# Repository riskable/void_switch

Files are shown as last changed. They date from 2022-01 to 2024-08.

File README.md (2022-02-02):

# Void Switch OpenSCAD Files
Parametric 3D printable magnetic separation contactless key switch and stabilizers (OpenSCAD files).  For the Kicad files see the [void_switch_kicad](https://github.com/riskable/void_switch_kicad) repo.

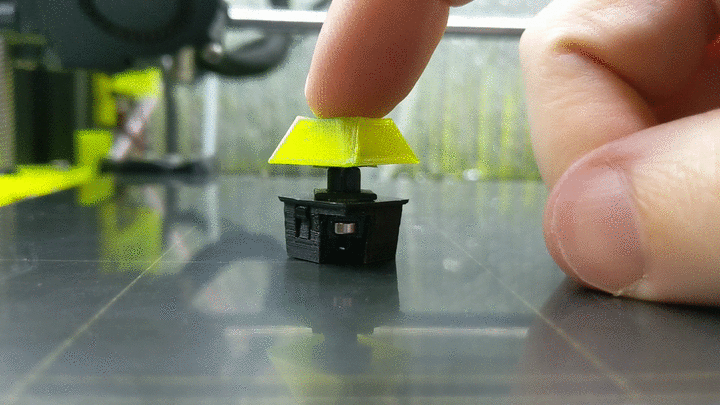
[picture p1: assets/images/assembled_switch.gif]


For a detailed overview of how Void Switches work see Chyrosran22's Teardown video:

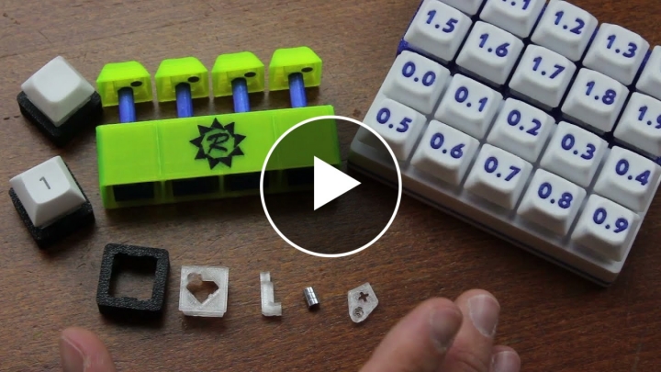
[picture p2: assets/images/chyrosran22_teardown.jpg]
Void Switch Teardown Video (https://youtu.be/H_Ym9528awM)


## BOM
Each switch needs three 4x2mm magnets (Note: Most cheap N35 magnets are actually 4x1.7mm *which is fine*) and the stabilizers require two 4x2mm magnets and some 18 gauge stainless steel wire (make sure it's magnetic; use the cheap stuff).  *Both of these are configurable*, however.  So if you want to make a switch that uses 3x2mm magnets you can do that (with a bit of work changing settings around).

For reference, there's two magnets in the switch itself (one in the sheath and one in the stem) and the levitator needs its own magnet.

## Prerendered files
Prerendered (4mm travel) void switch files are provided in .stl and .3mf format for 4x1.7mm (most common) and 4x2mm magnets with a `MAGNET_VOID` of 0.6mm.  This should make for an all-around decent set of parameters for doing quick tests and demos (to see how the switch feels).  For your own keyboard make sure you try out many different `MAGNET_VOID` values and also try changing the `STEM_TOLERANCE` value to see how you like tighter-fitting or looser-fitting switches.

## Parameters

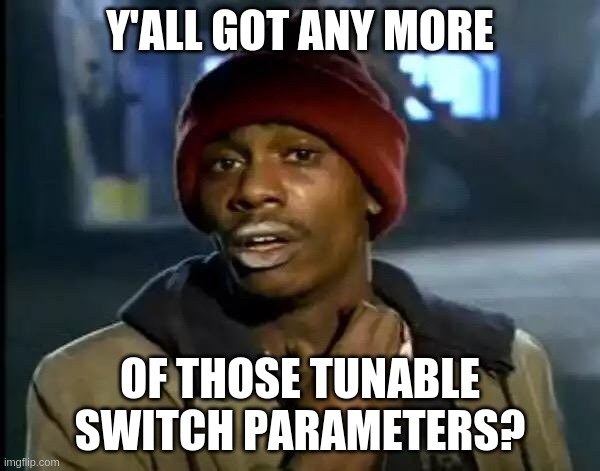
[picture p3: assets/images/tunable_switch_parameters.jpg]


Descriptions of what each parameter does are included in the .scad file and are easily referenced in the OpenSCAD customizer:

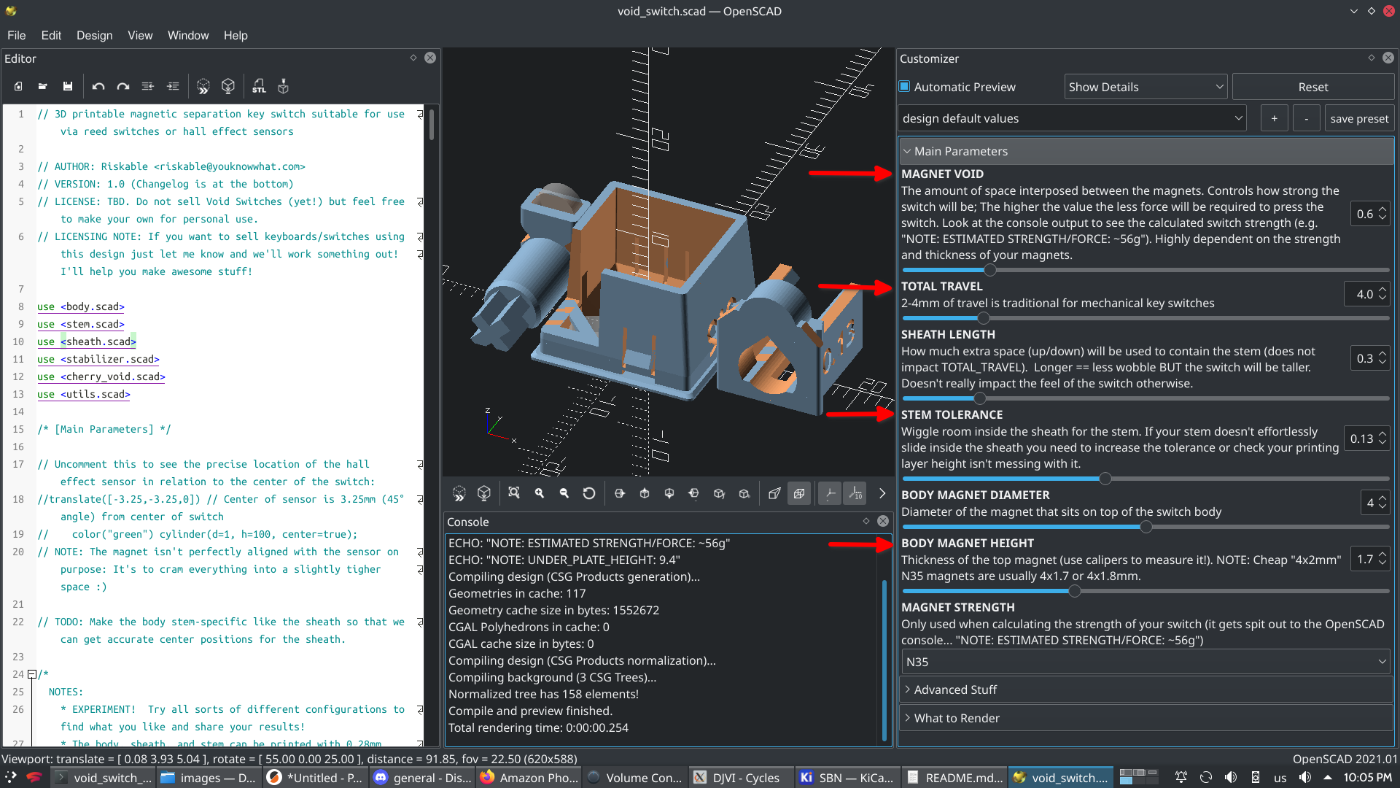
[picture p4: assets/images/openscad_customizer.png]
OpenSCAD Customizer


## Figuring out your switch force/strength
I've added several tables of switch strengths to the `utils.scad` and *pretty good* estimation of how strong your switch will be will show up in the OpenSCAD console.  Here's what it should look like (text enlarged and highlighted for effect):

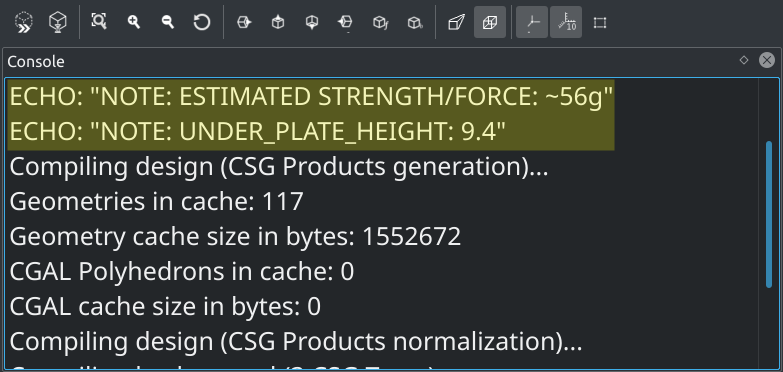
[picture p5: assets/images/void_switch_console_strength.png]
OpenSCAD Console Output


## Print settings
Print the switches and stabilizers at 0.16mm layer height.  This will ensure that the topmost layer of the interior of the sheath ends up with a "close enough" tolerance to your `STEM_TOLERANCE` setting.

The levitator can be printed at just about any layer height but 0.2mm is recommended.

**Note:** It is recommended that the switches be printed in PETG because it has the lowest coefficient of friction of all 3D printable filaments (0.22).  However, PLA also works just fine.  If you use the liquid/oil type of Super Lube w/Syncolon (PTFE) just about *any* filament will work great regardless.  Also note that *you can always just sand the stem* to your perfect level of polished smoothness (don't be lazy).

For reference, even terrible printers seem to do a fine job printined Void Switches.  Because of how the tactility works any bumps or scratchiness in the stems won't be easily felt.  Also, if you print in PETG it has self-lubricating properties when rubbing against itself (it sheds hydrogen atoms which causes a sort of thin molecular collapse at the surface, removing rough/uneven bits).

## Switch assembly
1. Place a magnet in the sheath (using groove jointed pliers makes this super quick and easy).
2. Snap the sheath into the body, pressing the magnet side in first (goes easier that way).
3. Place a magnet in the stem/slider, making sure it's in the correct orientation so as to be attracted to the magnet in the sheath.
4. Slide the stem/slider into the sheath from the underside of the switch.
5. Place a magnet in the levitator, ensuring that *it repels* the magnet in the sheath/body.
6. Place the levitator on the switch stem and then it's ready for a keycap.

**Note:** If you screw up the orientation of the magnets there's little holes so you can pop them out (and reverse them).

**Tip:** Once the sheath is snapped into the body I find it's best to give it a gentle squeeze with some pliers:

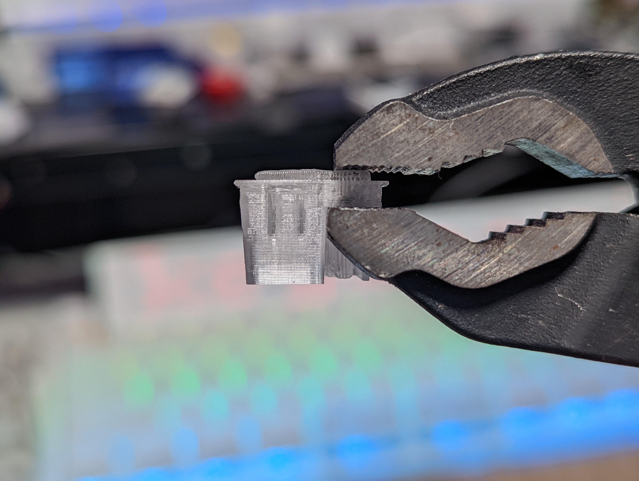
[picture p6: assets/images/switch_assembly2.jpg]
Using pliers on sheath and body together


**Tip:** If you find your magnets aren't staying put (and you don't want to fix the tolerances/print new ones) *you can always just use some glue*.  I find that CA glue (superglue) works great for this.  Just make sure to use the accelerator stuff or it might not stick as well.

## Video tutorials/gifs on how to aseemble Void Switches and stabilizers are coming soon!

I'll also be taking a series of photos and detailing the process here.

## What a keyboard using Void Switches looks like
Here's the keyboard I've been typing on every day for several months:

OpenSCAD Customizer

This is my Riskeyboard 70.  Since Void Switches are entirely contactless I made the case so that the entire top plate could be easily removed (it's magnetically attached with the same 4x2mm magnets used in the switches/stabs).  It makes it *super* easy to clean: Just take the top plate to your kitchen sink and give it a good scrub with soap and water!

## What keycaps to use with Void Switches

Void Switches (currently) use Cherry MX-compatible cross (+) stems so you can use any Cherry-MX compatible keycaps.  Having said that, it is highly recommended that you 3D print your own keycaps for Void Switches!  Try making your own with my [Keycap Playground](https://github.com/riskable/keycap_playground).  3D printed keycaps are superior to injection moulded keycaps in many ways:

 * PETG keycaps _feel_ fantastic!  They also have a very deep sound profile.  PETG is also a fantastic light pipe (that's what it was invented for!) which means multi-material prints with clear legends have the best clarity/brightness.  If you "just use white" PETG you can get very crisp, clear legends and the keycap will light up the same color as your LEDs.
 * PLA keycaps can be made using all sorts of interesting and amazing filaments (_they can have sparkles!_).  They have a sound profile similar to PBT keycaps (high pitch).
 * TPU keycaps are very easy on your fingers and very quiet.  Any 92A or harder TPU can be used for keycaps without any special modifications (yes, the stems will still work fine and won't be "floppy" or whatever).
 * If they break or get ugly or whatever _you can always print new ones_!  For pennies worth of filament!

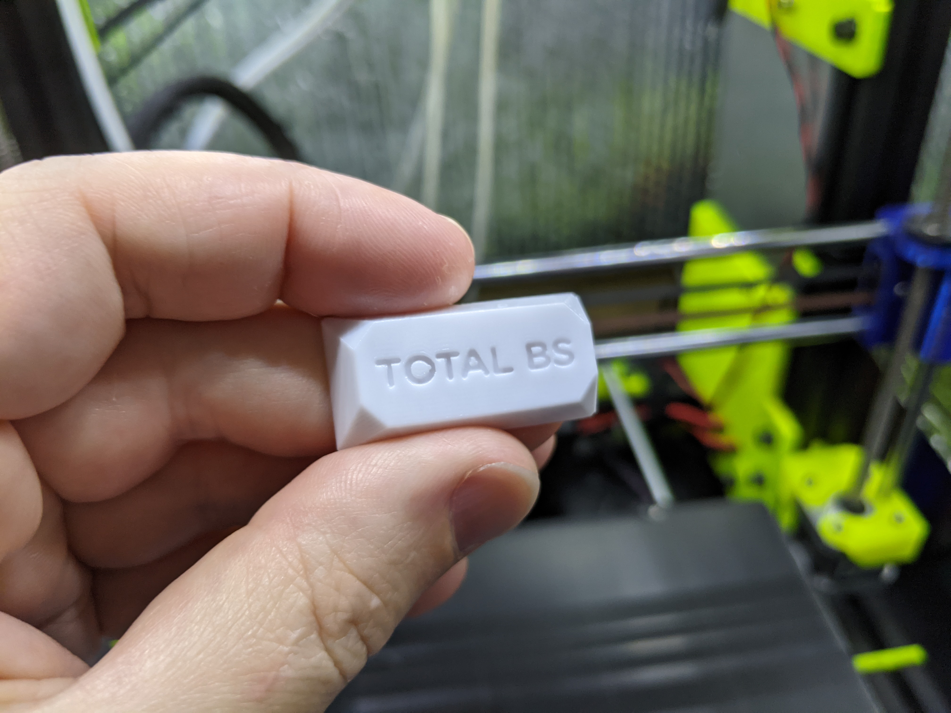
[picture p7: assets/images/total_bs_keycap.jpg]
White PETG TOTAL BS keycap


**NOTE:** Void Switches currently only support the Cherry MX-style cross (+) but support for other stem types can be added (places in the code were carved out for this).  If someone wants to add support for other types feel free to submit a PR.  It might be a better idea to make a stem/slider that simply accepts a "topper" that lets you attach/support an adapter that lets you put whatever stem type you want on there.

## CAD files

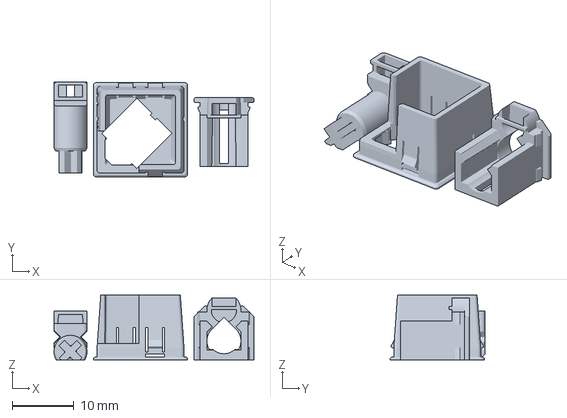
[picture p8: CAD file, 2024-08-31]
3mf/void_switch_2.0_4x1.8mm_1.0_magnet_void_0.2_sheath_length.3mf
32.4 x 15.4 x 10.5 mm

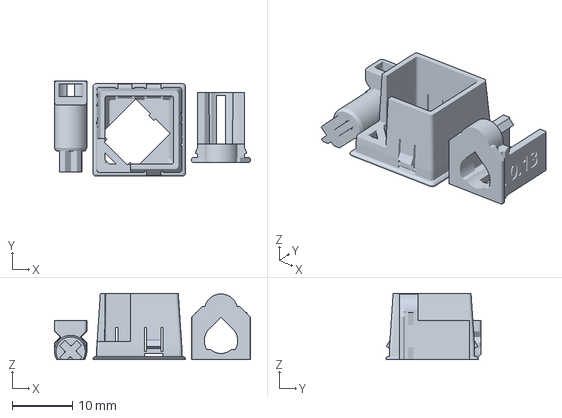
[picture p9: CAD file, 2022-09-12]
3mf/void_switch_4x2mm_0.9_magnet_gap.3mf
32.4 x 15.8 x 10.9 mm

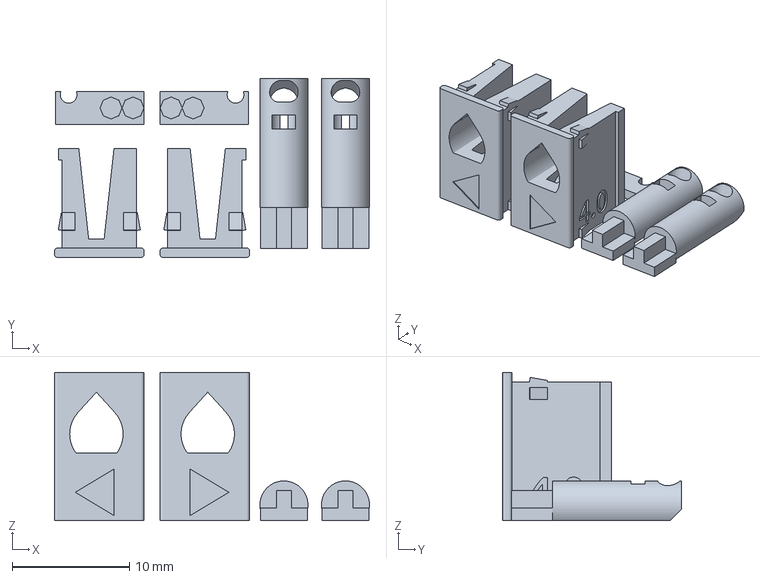
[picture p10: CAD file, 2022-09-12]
3mf/stabilizer_4x2mm_-0.1_void_4mm-travel.3mf
26.9 x 15.3 x 12.6 mm

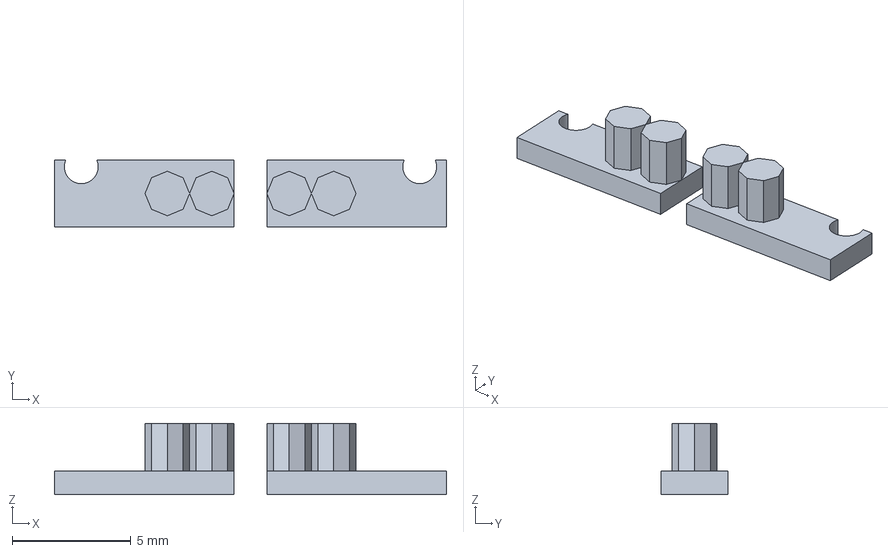
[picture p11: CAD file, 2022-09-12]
3mf/stabilizer_wire_clips.3mf
16.5 x 2.81 x 3.00 mm

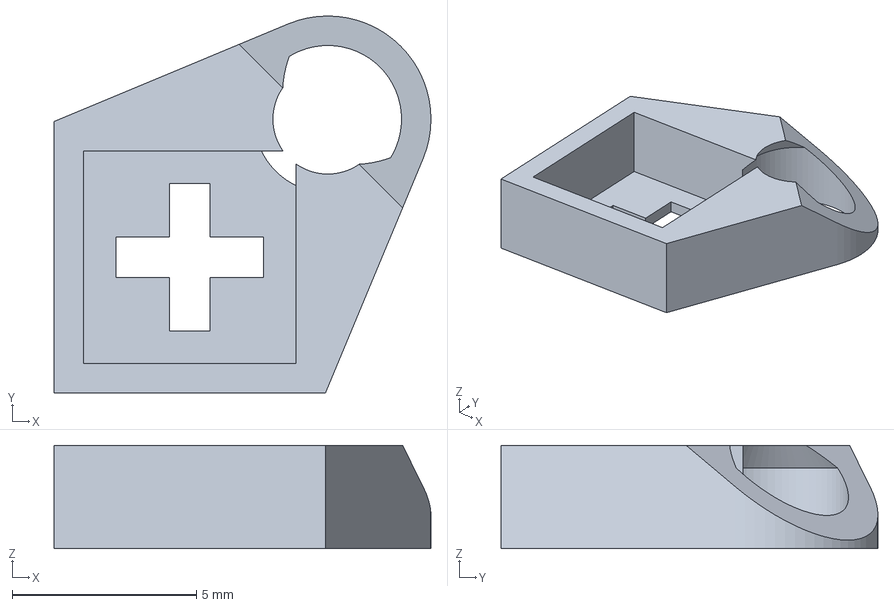
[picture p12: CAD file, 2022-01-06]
3mf/levitator.3mf
10.2 x 10.2 x 2.80 mm

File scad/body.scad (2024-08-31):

// Modules related to the main body of the switch

use <utils.scad>

// Constants
CHERRY_CROSS_LENGTH = 4; // Length of the - and the | in the +

// TODO: Document all these args
// The main housing of the switch that the sheath slides into
module switch_body(length, width, travel, taper=1.1, wall_thickness=1.4, sheath_wall_thickness=1.2, sheath_length=3, cover_overhang=1, cover_thickness=0.6, plate_thickness=1.5, plate_tolerance=0.2, stem_diameter=4.1, sheath_tolerance=0.2, lip_height=1, top_magnet_height=2, top_magnet_diameter=6, top_magnet_cover_thickness=-0.5, magnet_height=1.5, magnet_wall_thickness=0.5, magnet_tolerance=0.15, magnet_void=0.0, sheath_end_stop_thickness=0.8, corner_radius=0.5, droop_extra=0.2, sheath_clip_width=1.5, top_clip_hole_length=2.15, top_clip_hole_width=3.15, stem_tolerance=0.15, bridge_thickness=0.3, sheath_snug_magnet=true, sheath_inside_body=false, height=0) {
    total_travel = travel+top_magnet_height; // Actual total travel
    // How far into the body the stem shroud goes (so we can calculate depth)
    sheath_depth = (
        cover_thickness+sheath_length+total_travel-top_magnet_cover_thickness
        +magnet_height+magnet_wall_thickness*2+magnet_tolerance
        +magnet_void+sheath_end_stop_thickness); // NOTE: Does not include the lip_height on purpose
    body_height = height ? height : sheath_depth; // For clarity in the code
    note(str("BODY_HEIGHT: ", body_height));
    // NOTE: These two sheath variables need to match how they're handled in the actual sheath:
    sheath_width = stem_diameter+sheath_wall_thickness*2;
    sheath_height = stem_diameter+sheath_wall_thickness*2;
    snap_clip_protrusion = 0.2; // How much the little snap lip things stick out from the body (it gets rotate 45° so it's a little less, actually)
    snap_clip_thickness = 0.85; // How thick the clips are
    pin_diameter = 1.875; // Need to match the pin diameter used by the stabilizer clips
    clip_width = width/6;
    clip_side_hole_width = 0.35; // How wide the cutouts are beside each clip
    note(str("UNDER_PLATE_HEIGHT: ", body_height-cover_thickness));
    difference() {
        union() {
            // Generate the part of the body that overhangs the hole on the plate
            translate([0,0,cover_thickness/2])
                hull() { // This is tapered a bit to make removing the switch easier
                    squarish_rpoly(
                        xy=[length+cover_overhang-plate_tolerance/2, width+cover_overhang-plate_tolerance/2],
                        h=cover_thickness,
                        r=corner_radius, center=true);
                    translate([0,0,-cover_thickness/4]) squarish_rpoly(
                        xy=[length+cover_overhang*2-plate_tolerance/2, width+cover_overhang*2-plate_tolerance/2],
                        h=cover_thickness/2,
                        r=corner_radius, center=true);
                }
            // Generate the main body of the switch
            difference() {
                translate([0,0,cover_thickness]) hull() {
                    translate([0,0,plate_thickness/2]) squarish_rpoly(
                        xy=[length-plate_tolerance/2, width-plate_tolerance/2],
                        h=plate_thickness,
                        r=corner_radius, center=true);
                    translate([0,0,body_height-cover_thickness])
                        squarish_rpoly(
                            xy=[length/taper, width/taper],
                            h=cover_thickness/2, // Close enough
                            r=corner_radius, center=true);
                }
                // Cut out the corner so we don't have to worry about a large stem/magnet scraping the sides
                translate([
                  -length/3.75,
                  -width/3.75,
                  body_height/2+top_magnet_height+magnet_wall_thickness+droop_extra-top_magnet_cover_thickness+sheath_length
                  ])
                    cube([length/2,width/2,body_height], center=true);
                difference() {
                // NOTE: Because of the body taper we need to increase the wall thickness here slightly so that it prints well (don't want the slicer cutting off the corners).  That's why we have this "interior bulge" thing...
                    translate([0,0,-cover_thickness/2]) hull() {
                        // NOTE: The interior taper here is to give the wall-to-cover attachment a stronger bond (otherwise the top of the switch can break right off leaving you with a top and a hollow cube)
                        squarish_rpoly(
                            xy=[length-wall_thickness*3.75, width-wall_thickness*3.75],
                            h=cover_thickness/2,
                            r=corner_radius/1.5, center=true);
                        translate([0,0,body_height/4])
                            squarish_rpoly(
                                xy=[length-wall_thickness*2, width-wall_thickness*2],
                                h=cover_thickness/2,
                                r=corner_radius/1.5, center=true);
                        translate([0,0,cover_thickness+sheath_depth+magnet_height+wall_thickness/2])
                            squarish_rpoly(
                                xy=[length/taper-wall_thickness*1.25,
                                    width/taper-wall_thickness*1.25],
                                h=cover_thickness,
                                r=corner_radius/1.5, center=true);
                    }
                }
                // Add a little hole that ensures the bridging goes right
                // TODO: Make these hard-coded numbers like -4.7 take the size of the body into account...
                // Cut out the sides near where the stem presses against the magnet so it doesn't get caught on the sides
                translate([
                  -4.7,
                  -1,
                  top_magnet_height])
                    cube([2,1.6,top_magnet_height*2], center=true);
                translate([
                  -1,
                  -4.7,
                  top_magnet_height])
                    cube([1.6,2,top_magnet_height*2], center=true);
                if (cover_overhang) {
                    // Create a gap underneath the clips so they can move freely
                    gap_size = plate_thickness/2;
                    translate([
                        clip_width,
                        0,
                        cover_thickness/2+gap_size/2])
                            cube([
                                clip_width+clip_side_hole_width*2,
                                width*2,
                                gap_size], center=true);
                    translate([
                        -clip_width,
                        width/2,
                        cover_thickness/2+gap_size/2])
                            cube([
                                clip_width+clip_side_hole_width*2,
                                width/2,
                                gap_size], center=true);
                    // Cutout holes beside the clips so they can bend (slightly) easier when inserting
                    translate([
                        clip_width+clip_width/2+clip_side_hole_width/2,
                        0,
                        cover_thickness/2+travel/2+plate_thickness/2+bridge_thickness])
                            cube([clip_side_hole_width, width*2, travel], center=true);
                    translate([
                        clip_width-clip_width/2-clip_side_hole_width/2,
                        0,
                        cover_thickness/2+travel/2+plate_thickness/2+bridge_thickness])
                            cube([clip_side_hole_width, width*2, travel], center=true);
                    translate([
                        -clip_width-clip_width/2-clip_side_hole_width/2,
                        length/2+snap_clip_protrusion-cover_overhang/1.15,
                        cover_thickness/2+travel/2+plate_thickness/2+bridge_thickness])
                            cube([clip_side_hole_width, width/2, travel], center=true);
                    translate([
                        -clip_width+clip_width/2+clip_side_hole_width/2,
                        length/2+snap_clip_protrusion-cover_overhang/1.15,
                        cover_thickness/2+travel/2+plate_thickness/2+bridge_thickness])
                            cube([clip_side_hole_width, width/2, travel], center=true);
                    // Carve out a bit of the bridge that supports the clips so it can break away easier upon first insertion of the switch into the plate
                    translate([ // Back side left
                        -clip_width,
                        length/2-wall_thickness/1.55,
                        cover_thickness/2+plate_thickness/2+bridge_thickness/2])
                            cube([
                                clip_width+clip_side_hole_width*2,
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

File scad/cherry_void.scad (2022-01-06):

// Riskable's Cherry MX void/cutout module for making keyboard (top) plates and key switch testers

$fn = 32;

use <utils.scad> // Because it's nice to have rounded corners on these sorts of things

// AUTHOR: Riskable <riskable@youknowwhat.com>
// VERSION: 1.1 (Changelog is at the bottom)
// LICENSE: Creative Commons - Attribution - Non-Commercial (if you want to use it in a commercial setting/product just ask!)

// NOTES
/*
    * Feel free to use this .scad in your own projects to add proper Cherry MX-styled switch cutouts to keyboards, perhipherals, testers, or whatever you like.
    * You can just copy cherry_switch_void() into your own code if you like--it's entirely self-contained and reasonably small.  Just make sure to credit it, "// This module was written by Riskable:" or something like that =)
    * Actual Cherry MX Measurements:
        * Length/Width outside dimentions: 15.5mm x 13.95mm
        * Length/Width under the overhang (no "under" on one side though): 13.95mm x 13.95mm
        * In essence, it only overhangs on two sides and the basic cherry "hole" would be 14x14mm
*/

/* Creates the shape of a (proper) Cherry MX switch hole.
    height: The thickness, really.  Doesn't impact PLATE_THICKNESS
    x_extra: Extra (void) space on the X axis (e.g. to save some plastic). Doesn't change the top plate.
    y_extra: Extra (void) space on the Y axis.  Same thing as X.
    tolerance: Extra room on all sides (0.1 default should be good for most printers)
    plate_thickness: How thick the top plate will be. Typical Cherry MX plates are about 1.5mm thick.
*/
module cherry_switch_void(height=12, x_extra=0, y_extra=0, tolerance=0.1, plate_thickness=1.5, corner_radius=0.5) { // Cherry MX body is supposed to be 11.6mm
    switch_width = 15.6;
    switch_length = 14; // Slightly shorter because we're making an acurate profile (see below)
    center_space = 3.5; // Space between the cutouts on the sides of the switch
    sides_width = (5+center_space); // Taken from the Cherry MX developer PDF
    // Make the basic switch shape:
    cube(
        [switch_length+tolerance, switch_length+tolerance, height],
        center=true);
    // Profile for the sides:
    translate([0,sides_width/2,0])
        cube([switch_width-tolerance, center_space+tolerance, height], center=true);
    translate([0,-sides_width/2,0])
        cube([switch_width-tolerance, center_space+tolerance, height], center=true);
    // Fill out the rest with a solid cube so that there's a top plate + empty space beneath
    translate([0,0,plate_thickness])
        squarish_rpoly(
            xy=[switch_width+x_extra, switch_width+y_extra],
            h=height, r=corner_radius, center=true);
}

/*
CHANGELOG:
    1.2: Now using utils.scad with squarish_rpoly() instead of roundedCube since it's better (it's faster *and* I wrote it myself =).
    1.1: Now using roundedCube so the interior edges aren't so sharp.
    1.0: Initial release
*/

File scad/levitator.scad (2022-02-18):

// THE LEVITATOR - Goes under the keycap to provide a cusion of magnetic levitation

// AUTHOR: Riskable <riskable@youknowwhat.com>
// VERSION: 1.0 (Changelog is at the bottom)

/* NOTES:

    * The default configuration works with 4x1 through 4x2mm magnets (anything shorter than 2mm will end up stuck in there just fine--don't worry about it).
    * The default configuration will "eat" 0.4mm of your stem's cross height.  So keycaps won't be able to go all the way down (if you didn't print that part of the stem slightly longer to make up for it).  In testing, losing 0.4mm of height on the cross part of the stem makes absolutely no difference whatsoever.  The keycap still stays on just fine.  I wouldn't worry about it =)

*/

$fn = 64;

use <utils.scad>

// Configurables
LEVITATOR_THICKNESS = 0.4; // How thick the floor will be/how much of the cross part of the stem (+) gets eaten by THE LEVITATOR
WALL_THICKNESS = 0.8; // How thick around the edges you want it to be (0.8 is fine and fits under most keycaps)
STEM_TOLERANCE = 0.15; // How tight the cross-shaped cutout will be
MAGNET_TOLERANCE = 0.2; // Only used with MAGNET_HEIGHT (because we have some bridging)
MAGNET_DIAMETER = 4;
MAGNET_HEIGHT = 2;
MAGNET_DISTANCE = 3.75; // Distance from the center of the stem where the magnet goes

// Constants
CHERRY_CYLINDER_DIAMETER = 5.47; // Represents the keycap's stem (female side of the +)
CHERRY_CROSS_LENGTH = 4; // Length of the - and the | in the +
// We make the cross slightly thinner than normal to keep a tight fit:
CHERRY_CROSS_THICKNESS_X = 1.1; // Width of the - and in the + (Reality: 1.31)
CHERRY_CROSS_THICKNESS_Y = 1.1; // Width of the | in the + (Reality: 1.09)

levitator(MAGNET_DIAMETER, MAGNET_HEIGHT, magnet_distance=MAGNET_DISTANCE, magnet_tolerance=MAGNET_TOLERANCE, wall_thickness=WALL_THICKNESS, thickness=LEVITATOR_THICKNESS, stem_tolerance=STEM_TOLERANCE);
//levitator_double_sided(MAGNET_DIAMETER, MAGNET_HEIGHT, magnet_distance=MAGNET_DISTANCE, magnet_tolerance=MAGNET_TOLERANCE, wall_thickness=WALL_THICKNESS, thickness=LEVITATOR_THICKNESS, stem_tolerance=STEM_TOLERANCE);

// TODO: Finish making this as well as making a matching void space version for top plates:
// This is for the special situations with long ass/heavy spacebars: 
BACKFORCE_LENGTH = 30; // 15mm from the center of the switch on either side
BACKFORCE_WIDTH = 11; // Needs to fit inside/under the keycap but not terribly tight--just enough to prevent it from rotating
//uplifting_jigaroo(BACKFORCE_LENGTH, BACKFORCE_WIDTH, stem_diameter=CHERRY_CYLINDER_DIAMETER, magnet_diameter=4, magnet_height=2, magnet_tolerance=0, wall_thickness=1.2);

module levitator(magnet_diameter, magnet_height, magnet_distance=3.75, magnet_tolerance=MAGNET_TOLERANCE, wall_thickness=0.9, thickness=1, stem_tolerance=0.15) {
    // NOTE: stem_tolerance is the keycap stem; not the switch stem
    height = 2 + wall_thickness; // Just enough to grab the stem
    difference() {
        translate([0,0,height/2]) union() {
            // Main body of the thing
            hull() {
                // NOTE: The square-ish walls around the stem area are just to provide rigidity
                cube([
                    CHERRY_CYLINDER_DIAMETER+wall_thickness*2+stem_tolerance*2,
                    CHERRY_CYLINDER_DIAMETER+wall_thickness*2+stem_tolerance*2,
                    height], center=true);
                translate([magnet_distance,magnet_distance,0])
                    cylinder(d=magnet_diameter+wall_thickness*2, h=height, center=true);
            }
            // Body of the part that holds the magnet (hollowed out below)
            translate([magnet_distance,magnet_distance,0])
                cylinder(d=magnet_diameter+wall_thickness*2, h=height, center=true);
        }
        translate([0,0,-5]) cherry_cross(length=10); // Just don't die on it
        translate([0,0,height/2+thickness+wall_thickness/2]) // Stem cutout
            cube([
                CHERRY_CYLINDER_DIAMETER+stem_tolerance*2,
                CHERRY_CYLINDER_DIAMETER+stem_tolerance*2,
                height+wall_thickness], center=true);
        translate([magnet_distance,magnet_distance,(magnet_height+magnet_tolerance)/2-0.01]) {
            cylinder(d=magnet_diameter, h=magnet_height+magnet_tolerance, center=true);
            // So we can pop the magnet out if we screw up which pole is facing down:
//            rotate([0,0,45])
//                cube([magnet_diameter/3,magnet_diameter/3,100], center=true);
        }
        // Make an angled hole in the top that stops the magnet from coming out while also letting you push it out if needed to flip it around
        translate([magnet_distance,magnet_distance,wall_thickness/2+(magnet_height+magnet_tolerance)-0.01])
            cylinder(d1=magnet_diameter, d2=magnet_diameter/1.5, h=wall_thickness, center=true);
        // Cut off a few bits here and there so it can fit under more keycaps
//        translate([magnet_distance*2+wall_thickness/1.25,magnet_distance*1.25,magnet_diameter/2])
//            cube([magnet_diameter, magnet_diameter*2, magnet_diameter*2], center=true);
//        translate([magnet_distance*1.25,magnet_distance*2+wall_thickness/1.25,magnet_diameter/2])
//            cube([magnet_diameter*2, magnet_diameter, magnet_diameter*2], center=true);
        translate([magnet_distance*1.5,magnet_distance*1.5,magnet_diameter/1.35])
            rotate([0,-50,45])
                cube([magnet_diameter, magnet_diameter*2, magnet_diameter*2], center=true);
    }
}

module levitator_double_sided(magnet_diameter, magnet_height, magnet_distance=3.75, magnet_tolerance=MAGNET_TOLERANCE, wall_thickness=0.9, thickness=1, stem_tolerance=0.15) {
    // NOTE: stem_tolerance is the keycap stem; not the switch stem
    height = 2 + wall_thickness; // Just enough to grab the stem
    difference() {
        translate([0,0,height/2]) union() {
            // Main body of the thing
            hull() {
                // NOTE: The square-ish walls around the stem area are just to provide rigidity
                cube([
                    CHERRY_CYLINDER_DIAMETER+wall_thickness*2+stem_tolerance*2,
                    CHERRY_CYLINDER_DIAMETER+wall_thickness*2+stem_tolerance*2,
                    height], center=true);
                translate([magnet_distance,magnet_distance,0])
                    cylinder(d=magnet_diameter+wall_thickness*2, h=height, center=true);
                translate([-magnet_distance,-magnet_distance,0])
                    cylinder(d=magnet_diameter+wall_thickness*2, h=height, center=true);
            }
            // Body of the part that holds the magnet (hollowed out below)
            translate([magnet_distance,magnet_distance,0])
                cylinder(d=magnet_diameter+wall_thickness*2, h=height, center=true);
        }
        translate([0,0,-5]) cherry_cross(length=10); // Just don't die on it
        translate([0,0,height/2+thickness+wall_thickness/2]) // Stem cutout
            cube([
                CHERRY_CYLINDER_DIAMETER+stem_tolerance*2,
                CHERRY_CYLINDER_DIAMETER+stem_tolerance*2,
                height+wall_thickness], center=true);
        translate([magnet_distance,magnet_distance,(magnet_height+magnet_tolerance)/2-0.01])
            cylinder(d=magnet_diameter, h=magnet_height+magnet_tolerance, center=true);
        translate([-magnet_distance,-magnet_distance,(magnet_height+magnet_tolerance)/2-0.01])
            cylinder(d=magnet_diameter, h=magnet_height+magnet_tolerance, center=true);
        // Make an angled hole in the top that stops the magnet from coming out while also letting you push it out if needed to flip it around
        translate([magnet_distance,magnet_distance,wall_thickness/2+(magnet_height+magnet_tolerance)-0.01])
            cylinder(d1=magnet_diameter, d2=magnet_diameter/1.5, h=wall_thickness, center=true);
        translate([-magnet_distance,-magnet_distance,wall_thickness/2+(magnet_height+magnet_tolerance)-0.01])
            cylinder(d1=magnet_diameter, d2=magnet_diameter/1.5, h=wall_thickness, center=true);
        // Cut off a few bits here and there so it can fit under more keycaps
        translate([magnet_distance*1.5,magnet_distance*1.5,magnet_diameter/1.35])
            rotate([0,-50,45])
                cube([magnet_diameter, magnet_diameter*2, magnet_diameter*2], center=true);
        translate([-magnet_distance*1.5,-magnet_distance*1.5,magnet_diameter/1.35])
            rotate([0,50,45])
                cube([magnet_diameter, magnet_diameter*2, magnet_diameter*2], center=true);
    }
}
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

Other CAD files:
3mf/void_switch_4x1.7mm_0.9_magnet_gap.3mf
3mf/void_switch_4x2mm_0.6_magnet_gap.3mf
3mf/void_switch_4x1.7mm_0.6_magnet_gap.3mf
scad/sheath.scad
scad/sheath_negative.scad
scad/stabilizer.scad
scad/stem.scad
scad/utils.scad
scad/void_switch.scad
stl/levitator.stl
stl/stabilizer_4x2mm_-0.1_void_4mm-travel.stl
stl/stabilizer_wire_clips.stl
stl/void_switch_4x2mm_0.6_magnet_gap.stl
stl/void_switch_4x2mm_0.9_magnet_gap.stl

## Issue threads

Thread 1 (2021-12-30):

Love these switches

C1ARKGABLE, 2021-12-30:
Saw [this YouTube video](https://www.youtube.com/watch?v=H_Ym9528awM) and had to find where I could get these switches. I'd love to try printing a low profile set.

Have you thought about potentially adding elector magnets to tune the key characteristics on the fly?

Keep up the great work

C1ARKGABLE, 2021-12-30:
Not an issue, just wanted to comment

riskable, 2022-01-03:
Haha I made this repo *in preparation* for releasing my switch files.  They're not quite ready yet.  Very soon though :smile:

Closed 2021-12-30.

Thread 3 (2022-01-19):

Just a question: Minimum practical size?

kubycsolutions, 2022-01-19:
Lovely design, and many thanks for parameterizing and documenting it so well.

Apologies if I've missed this one in the docs: Have you done any experiments to see what the minimum center-to-center distance could be while still operating well? I have an button-matrix application where that's about half an inch; full-size keyboards run closer to 3/4".

riskable, 2022-01-20:
The distance from the center of the switch to the magnet is 3.25mm (it's hard coded--for now) and the diagonal width of the sheath is ~12mm.  So the minimum width/length of the switch with default settings is going to be 12mm+some space for wall thickness so it *should* fit within 0.5inches (12.7mm).

Another thing you can do is use 3x2mm magnets instead of 4x2mm...  Then you can decrease the `STEM_DIAMETER` and you'll end up with a sheath that's skinnier.  You can also try setting `STABILIZER_STEM = true;` which will give you a stem with a + that's flat instead of at a 45° angle.  This would enable you to place the sheath into the body (or just a top plate with the correct cutout shape) horizontally instead of vertically.  Just make sure your sensors are 3.25mm away from the center of the footprint and it should work fine.  In this situation you'd be making a switch that had the magnet just below or above the center of the switch instead of diagonally in the corner.

There's all sorts of other values you can play with to squeeze the switch into a tighter space like WALL_THICKNESS, MAGNET_WALL_THICKNESS, etc etc.  You can also use a smaller magnet in the stem but keep the body magnet the usual 4x2mm size (mix & match).  You *may* have to go into sheath.scad and fudge a few of the values to make things line up though.  If you read the comments I have loads of info about places where that might be necessary for certain types of adjustments.

kubycsolutions, 2022-01-20:
Many thanks once again!--Sent from palmtop; apologies for any auto-incorrections.() | ASCII Mail Campaign/\ | Stamp out HTML mailOn Jan 20, 2022 9:36 AM, Riskable ***@***.***> wrote:

The distance from the center of the switch to the magnet is 3.25mm (it's hard coded--for now) and the diagonal width of the sheath is ~12mm.  So the minimum width/length of the switch with default settings is going to be 12mm+some space for wall thickness so it should fit within 0.5inches (12.7mm).

Another thing you can do is use 3x2mm magnets instead of 4x2mm...  Then you can decrease the STEM_DIAMETER and you'll end up with a sheath that's skinnier.  You can also try setting STABILIZER_STEM = true; which will give you a stem with a + that's flat instead of at a 45° angle.  This would enable you to place the sheath into the body (or just a top plate with the correct cutout shape) horizontally instead of vertically.  Just make sure your sensors are 3.25mm away from the center of the footprint and it should work fine.  In this situation you'd be making a switch that had the magnet just below or above the center of the switch instead of diagonally in the corner.

There's all sorts of other values you can play with to squeeze the switch into a tighter space like WALL_THICKNESS, MAGNET_WALL_THICKNESS, etc etc.  You can also use a smaller magnet in the stem but keep the body magnet the usual 4x2mm size (mix & match).  You may have to go into sheath.scad and fudge a few of the values to make things line up though.  If you read the comments I have loads of info about places where that might be necessary for certain types of adjustments.

—Reply to this email directly, view it on GitHub, or unsubscribe.Triage notifications on the go with GitHub Mobile for iOS or Android.

You are receiving this because you authored the thread.Message ID: ***@***.***>

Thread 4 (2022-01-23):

Licensing

RussNelson, 2022-01-23:
Hi. I was the Open Source Initiative VP in charge of Licenses for 11 years. Open Source licenses protect the code by restricting the right to copy with copyright permissions. By default, you have no right to copy, but if you comply with the terms of the license (whatever they may be), you can redistribute the work, whether modified or original.

What copyright does not let you do, as you might guess from the "copy" part of copyright, is restrict use of a work. If someone has legally obtained a copy of a work, they can use it any way they want. In particular, people can use your work to create void_switches and sell them.

In order to restrict how people can use the work, you would have to have a patent on using three magnets to create a key with the desired characteristics. The AT&T key which uses two magnets and a spring is a different thing. Only a court could tell you whether your invention infringes on the AT&T key, if indeed they patented it. If there is no patent, or it's expired, then you're home free to patent it yourself. I recommend against doing that, though, because it takes a long time and lots of money and in the end a patent is just permission to sue and a likelihood that you will win.

The worst circumstance would be if somebody has a patent on using three magnets as you have done. I don't even want to think about how awful that would be.

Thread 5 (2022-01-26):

Question: how is your PCB/circuit?

ianliu, 2022-01-26:
Hi Riskable,

First I would like to say: MOTHER F*#$%! GENIUS design! Congrats!

Second, how is your circuit implemented? Do you need a matrix of analog pins for this keyboard to work? Is it even possible to make an analog matrix?

How do you measure each key? Is there a coil under each key?

Thanks!

RussNelson, 2022-01-27:
There is no Matrix unless you use Reed switches. If you use hall effect
sensors, there is one for key, and you need one bit of IO per key.

On Wed, Jan 26, 2022, 18:47 Ian Liu Rodrigues ***@***.***>
wrote:

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

DeadlySurgeon, 2022-01-27:
Any idea what hall effect sensors would be good to use? I looked at the kicad repo and there doesn't seem to be any recommendations.

RussNelson, 2022-01-27:
https://www.amazon.com/gp/product/B09PG3PGH6/ref=ppx_yo_dt_b_asin_title_o04_s00?ie=UTF8&psc=1

DeadlySurgeon, 2022-01-28:
@RussNelson Those are THC. Any clues on SMDs, like in the example board repo?

riskable, 2022-02-07:
For my boards I've mostly been using OH49E-S hall effect sensors.  They're cheap and readily available.

Also note that I'm making a tutorial series talking about how to make your own analog keyboard PCB (parts 1 and 2 are up): https://youtu.be/TfKz_FbZWLQ

udif, 2022-02-16:
Looking at https://github.com/riskable/void_switch_kicad/blob/main/symbols/49e.kicad_sym I see you also found:

https://lcsc.com/product-detail/Magnetic-Sensors_GoChip-Elec-Tech-Shanghai-GH39FKSW_C266230.html
It seems to be ~30% cheaper, at 0.1306$/unit (150PCS) vs 0.1984$/unit (100PCS).

Comparing the datasheet, it seems to have a compatible pinout, but it is slightly less sensitive (1.8mv/GS vs 2mV/GS for OH49E-S), and typically consume 6mA vs 4.2mA for the OH49E-S, which might be an issue in a keyboard with close to 100 switches, esp. if you want to power it from USB.

Do you have any actual experience with this part?

riskable, 2022-03-18:
@udif Yes, I swap out OH49E-S for GH39FKSW based on what's available all the time.  My firmware doesn't really care much about the sensitivity and both are approximately using the same amount of power when powered at 3.3V.

Closed 2022-03-23.

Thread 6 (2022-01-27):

Sheath does not appear to fit into body on default settings

Exxion, 2022-01-27:
I was excited to try these keys out (and still am), but when I printed one up, the sheath did not even come close to snapping into the body, even after considerable filing and use of pliers. I tried again (with the recommended layer height this time) and got the same result. Then I checked out the render in OpenSCAD, and found that at the default settings, it shows a considerable negative clearance between the sheath's magnet holder and the body's pocket for it. The clearance around that part does not appear to become positive until the sheath tolerance setting is around 0.4. Am I doing something wrong, or did an error make its way into the final files?
I'm confident in the quality of my printer, though somewhat less confident in the quality of my filament.

RussNelson, 2022-01-27:
I was able to print a key from the supplied .STL files. I have 4x1.7 magnets.

Exxion, 2022-01-27:
And the sheath snapped all the way in, with the sheath's magnet holder inside a pocket in the body? I just measured the provided STL file, and the hole the sheath is supposed to fit into is ~0.15mm shorter than the sheath, along the axis through the center of the magnet holder and the opposite corner of the body, not counting the notch on the side of the hole opposite the magnet holder.

RussNelson, 2022-01-27:
Well, here's the thing: I printed both the 4x2 magnet STL and 4x1.7 magnet STLs, then didn't keep track of which ones I was assembling. :-1: However, that only changes the thickness of the magnet holder, which shouldn't affect the dimensions of the sheath or body.

Exxion, 2022-01-27:
Yeah, that shouldn't change anything as far as this goes.
My filament indeed wasn't very good, and switching to a better filament improved the situation slightly, but there's still no way it would fit for me without either setting that 8 to 64 or greatly increasing the sheath tolerance. Using the better filament *and* setting the 8 to 64 made it very nearly possible. Close enough that at that point the remaining issue is almost certainly on my end.

riskable, 2022-02-07:
It's supposed to be nice and tight.  That's why I have a picture of me using pliers to press the two together.  You should still be able to do it by hand though.  I've printed thousands of these things and never had a problem.  You can change line 208 in body.scad from `fn = sheath_inside_body ? 64 : 8;` to just `fn = 64;` if you want a looser fit.

masterjuggler, 2022-02-08:
It helped me to tilt the sheath down slightly toward the round part to press that in first. Occasionally I had to chamfer the edge to get it started, but once it starts going in it'll snap into place with pliers. I made a tester batch of a bunch of different actuation weights and stroke lengths that way.

Exxion, 2022-02-08:
I dried out my filament and it fit, albeit not easily. I'm surprised it fits together with that much negative clearance in the STL! Regardless, apologies for the trouble.

Closed 2022-02-08.

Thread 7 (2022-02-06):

What hall effect switch from where?

RussNelson, 2022-02-06:
I got some 3144 hall effect switches, which seem to be too sensitive. I'd really like switches which have a large operating point. The 3144's (at least as characterized by Allegro MicroSystems) have no typical rating, and can operate anywhere between 70 Gauss and 350 Gauss. The 3143 switches seem to require a lot more magnetism aka closeness. Also, the hysteresis, 55 G, is killing me. Even if I can find a distance that the magnet operates the switch, it doesn't get far enough away to release the switch.

What hall effect switch are you guys using, and where did you get it from?

RussNelson, 2022-02-06:
Hmmm.... I have found that if I lay the sensor down, and pass the key's magnet past the top of the sensor, I can reliably sense a key press:

https://user-images.githubusercontent.com/1156994/152701435-1290b592-40a0-4849-b3f0-5bf49dcf0723.mp4

Closed 2022-02-06.

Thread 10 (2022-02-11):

non-flat keyboard?

RussNelson, 2022-02-11:
I use an ergo keyboard, the Kinesis Essential. It has two flat mini-keyboards (ctrl/alt/backspace/delete/home/end) and (alt/ctrl/space/enter/pageup/pagedown), and two dishes keyboards. Frankly, dishing and PCBs are incompatible .... _until now_! If you print the key retainers in a dish shape, and use through-hole 49E hall sensors, you can vary the length of the leads so they are different heights above the PCB to match the dishing of the key retainers.

I'll try it and let you know how it goes.

Zentheon, 2024-07-22:
I just found out about void switches and am currently using an ergo kb myself. Any updates on this project?

RussNelson, 2024-07-22:
The above is one of my many projects, which one of which has made little progress beyond printing a base and printing the keys.

Zentheon, 2024-07-22:
Totally get that, haha. Thanks for the quick response!

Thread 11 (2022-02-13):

Switch tends to stick when bottomed out

JBP113, 2022-02-13:
I have all of the magnets in properly and I have found on my test switch before I print anymore of them that the switch has a tendency to stay down sometimes, any tips?

RussNelson, 2022-02-14:
Are you sure you have the magnet polarity correct? The top pair should repel and the bottom pair should attract.

JBP113, 2022-02-14:
I had them correct, I didn't realize my print came out rough so there was to much friction.

Closed 2022-02-14.

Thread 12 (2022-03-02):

Issues with 5mm magnets

scrouthtv, 2022-03-02:
Hello,

I tried creating some switches with 5mm magnets.
The wall around the magnet in the stem seems to be too small:
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

Indeed, when I put the magnet in, one of the walls simply snapped off.

Is there any way to increase the wall size at this position?

Thanks in advance :)

riskable, 2022-03-18:
If you plan to use magnets larger than 4mm you'll need to adjust the `STEM_DIAMETER` so that the walls surrounding the magnet don't bulge out like in your screenshot.  You may also need to make some adjustments here and there in other places but I'm not 100% certain. It's been a long time since I messed with different magnet sizes.

Closed 2022-03-19.

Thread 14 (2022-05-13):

Resin Teflon Mod

Naturalog-data, 2022-05-13:
What I noticed is the friction with resin prints. First I decreased the diameter of the stem and I glued a layer of teflon tape onto the stem. Then I applied some dielectric grease. It now works smoothly with resin prints!

Dracozny, 2022-05-14:
you may notice the need to reapply the grease from time to time. I find Dielectric tends to gum after a period of time.

riskable, 2022-05-17:
If you use the liquid form of Super Lube "Multi-use synthetic oil" (with Syncolon/PTFE part 51004) you can just drizzle it on there really quickly and it lasts a couple weeks.  When it stops working that's when you know it's time to clean those keycaps off in the sink with a scrub brush + soap and water.  That sink cleaning process also removes all the grease/lube so it'll need to be re-applied.  With actual grease you kinda have to "paint it on" with a brush but with the liquid stuff you just squeeze a drop on to each switch all in one go while it's flipped upside down and it takes like 2 minutes to do a whole keyboard (which is like, *nothing* haha).

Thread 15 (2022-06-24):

Switching hall effect sensors on/off

TAImatem, 2022-06-24:
I am somewhat concerned with power consumption given that each sensor seems to consume around 4-6mA. I wonder if it would be possible to turn on hall effect sensors cluster-by-cluster while polling. Maybe like turn on the cluster -> wait about 0.1ms -> poll the cluster.

Managed to find Texas Instruments design paper that involves duty cycling, they use 50-60mcs delay (although they use their, own significantly more expensive DRV5033 sensors).
www.ti.com/lit/ug/tidub69/tidub69.PDF (nice)

That approach could probably be used to simplify the circuit as well

TAImatem, 2022-06-24:
Although I guess you can just as easily turn on all hall sensor -> wait -> poll -> turn all off. I suspect polling time would take significantly less time than waiting for hall sensors to stabilize. And in case of strict power requirements (like wireless keyboard) you can cut polling rate to 10 times a second when idling (should be enough to be perceived as immediate when user resumes typing and would consume around 1/1000 of total hall sensors power (assuming duty cycle length would be at 0.1ms))

TAImatem, 2022-06-24:
That said, even sk6805 (at 15mA), not to mention ws2812 (at 60mA), would be consuming significantly more power at 100%. Though I really doubt anyone would enjoy 5-21W of backlight (but hey, you could use keyboard as desk lamp 🤣)

riskable, 2022-09-12:
This is something I've been researching a lot...  I doubt doing power-efficient *linear* hall effect sensing is realistic because those sensors need to much time to "settle" after power on before you can take reliable measurements.  Hall effect *switches* on the other hand can be found in packages that use so little power as to be nearly non-existent.

The trouble with using such ultra low power hall effect switches is that they can be expensive and you also need to carefully calibrate the position of the switch above the sensor and have a fixed actuation distance (it couldn't be adjustable).  If you're going to go that far I was thinking it might make more sense to just add a tiny conductive rubber pad to the bottom of the stem and just turn it into a contact switch that smacks into some tracks on the PCB to form a circuit (like a game pad button).

TAImatem, 2022-09-12:
IMO what you proposed would give a rather terrible feel, partially because you can't really have any after-travel, and something tells me there's gonna be a noticeable jitter (admittedly reed switches also have up to 1ms of jitter). Also you might have to perform a rather frequent throughout cleaning. And it would be pretty hard to implement on non-planar keyboards.
IMO if one is willing to compromise on analog input he/she could use optical switches: they don't seem to be super expensive (on AliExpress they seem to go around 1$ for 10pcs or 20$ (smh) for 100pcs) and come with convenient mounting holes (i.e. ITR20005). You would still need to powercycle them, but turn-on/off time should be around 10mcs (advised power consumption seems to be around 20ma, but can be lower). Optical switches do limit material choice significantly though since for best results casing should be able to block outer IR light and stem would have to at least have some sort of IR-blocking shutter attached to it. The switches would also have to have a hole in them and that can significantly worsen metallic dust problem.

I personally would rather powercycle ordinary linear hall sensors line-by-line if latency is not an issue since it comes with additional benefit of simplified circuitry (sensor outputs can be joined in columns through diods and/or transistors). If my dso138mini supports external trigger I might do some experimentation on turn on times: basically just use a square waveform as Vcc, set a magnet at constant distance and see how long it will take on average for Vout to settle; Repeat the procedure with various distances

riskable, 2022-09-24:
I have an update to this!  I did some testing with a through-hole 49E linear hall effect sensor and I was able to figure out that you can ignore the settling time for the most part *as long as you remain consistent* with how long you keep the sensor powered on.

Basically, if you power on the sensor and then ~3 microseconds later you take a reading the value could be 2300 instead of 2500 (just an example).  However, *it'll always be off by that same amount*.  There doesn't seem to be much variation in how much it's "off" (for the same length of time).  I only tested the one sensor but powering it on and then reading it immediately thereafter results in the same value every time--even though it'll be like 100-200mV away from it's "settled" value.

Caveat:  The sensor in question did not have any capacitors and was running off my USB hub's 5V supply (which is strangely exceptionally stable--on that one USB hub anyway hehe).

I suspect that if I did more testing I'd see more voltage wobble up/down if I waited much longer than just 3 microseconds before taking a reading.  However, since the RP2040 board I was testing with can turn a GPIO pin on (that went through a non-MOSFET transistor turned on the sensor) and read an analog pin within 3 microseconds (~1µs to set the GPIO pin to HIGH and 2µs to read) the values were more consistent than if you were doing it through say, an asynchronous process/loop mechanism.

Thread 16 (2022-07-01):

5mm magnet troubles

Spectredemortis, 2022-07-01:
For whatever reason, I'm having a very hard time getting the sheath to snap in to the body with 5x2mm magnets. I've adjusted every setting in the scad file that I would need to, I think.
Any tips or suggestions on getting this to work?

vdubedout, 2022-09-01:
Hi there,
I was able to make it work with 6x3 magnets by only adjusting the two magnets settings and re-cutting the stem that was printed too high. Can you put some pictures of what's the problem?

owengnius, 2023-06-16:
hey @vdubedout  can you send me the stl files meant for the 6x3 magnets please?

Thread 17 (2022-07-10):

switch without base?

RussNelson, 2022-07-10:
I want to make a one-handed chording keyboard using these switches. They need to be at slight angles to each other to reflect the angle of movement of the fingers. When relaxed the fingers as slightly separated but when you pull them in, they get closer. That's part of the angle that needs to be different for each switch. They also need to be closer together than they would be using the body.

Has anybody come up with a modification that cuts just the hole for the sheath, so I can create a multi-switch body by cutting multiple holes at the correct orientation?

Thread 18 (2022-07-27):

Dimmensions of the switch?

andresteare, 2022-07-27:
Hi! do you have the dimensions of the switch? of any of the parts
When I print it, the keycap mount is much smaller than the mount in the stem, also the housing of the switch doesn't fit a plate so if you have those specifications I would be very usefull to alter my parameters

riskable, 2022-09-12:
The default switch body width/length is 18mm.  If you're having trouble fitting things together it's likely that your printer isn't printing dimensionally accurate prints.  It's an easy thing to fix:  Just calibrate your esteps (just search it up; there's a million tutorials).

I designed the switch body so that it would fit in a standard Cherry MX plate cutout.  If your switches don't fit in one then your printer is probably waaaaaay off in terms of dimensional accuracy.

andresteare, 2022-09-22:
thanks for the answer! I'll take a look on my printer calibration parameters and try again

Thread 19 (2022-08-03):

MAGNET_WALL_THICKNESS not honored in "sheath"

ivanpointer, 2022-08-03:
Setting `MAGNET_WALL_THICKNESS` changes the body, but in the sheath, the value is hard-coded, creating issues with snapping the sheath and body together when this value is changed - especially decreased.

The solution is to simply specify this value on the sheath in void_switch.scad - the function already has a parameter for it, but because it's not passed, the function uses the hard-coded default of 0.5.

I'll be submitting a PR for this shortly.

ivanpointer, 2022-08-03:
Submitted PR #20.

Closed 2022-09-12.

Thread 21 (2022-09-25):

Stupid Question: Can you use any case and pcb?

Metal-Toilet, 2022-09-25:
I've read confilcting things in different articles. Can you just use any pcb and case that fits void switches? Or do I need something special? Where would I buy that something special.

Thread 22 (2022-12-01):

Help with how the stabilizer works?

richardlyf, 2022-12-01:
Hi! I'm a bit confused by how the stabilizer is supposed to work, specifically how the magnets are supposed to interact to help push the stem back up after a key is pressed. Is the 4x2mm magnet in the stabilizer body supposed to pull on the stainless steel wire itself? A lot of the stainless steel wires I found at Michaels are actually not magnetic. Is it supposed to pull on smaller 2x1mm magnets in the stem?
Thanks for your help!

catgirlkara, 2025-01-11:
I am also confused by the stabilizer that I printed.

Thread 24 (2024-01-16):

How do the presses register

HoloGrainCode, 2024-01-16:
I would like to 3D print this and was wondering how this registers presses

Kerman-ap, 2024-07-26:
From what I understand the sensor is on the pcb

RussNelson, 2024-07-26:
When the magnet gets close enough to the hall effect sensor, that registers a press. There are two ways to do this: using a digital hall effect sensor or an analog sensor. The trouble with digital is that it has a fixed set point, and depending on the exact position of the magnet and sensor, that set point may not trigger at the right point. That is why Riskable is using analog sensors, an analog multiplexor, and an A/D converter to measure the voltage out of the sensor and thus the exact position. Then the software calibrates each key to get the most accurate trigger point.

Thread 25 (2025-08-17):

[Idea] ElectroMagLev Keyboard Switch: use tiny electromagnet for adjustable resistance and rebound

FluorescentHallucinogen, 2025-08-17:
What about replacing one of the permanent magnets (obviously in the body of the switch, not axis) with a tiny electromagnet?

The strength of the electromagnet could be controlled by current. It could even be variable and depend on the Hall effect sensor or optical sensor readings.

I would call it _ElectroMagLev_, short for _ElectroMagnetic Levitation_.

Imagine being able to fully customize the haptic feedback, adjust not just the actuation point, but also the resistance and rebound speed of each key using a user-friendly graphical interface e.g. via mouse (Force-Travel Curve Editor). See image.

This level of customization allows users to emulate the behavior of almost any keyboard switches available on the market or create a truly personalized typing experience, tailored to their specific needs and preferences.

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

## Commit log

2021-12-24 Update README
    Just clarified that the Kicad files will be in a separate repo
2022-01-06 Added all the .scad files along with some pregenerated .stl and .3mf files. Also updated the README.
    [body.scad, cherry_void.scad, levitator.3mf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]
2022-01-06 fix switch_assembly image in readme
2022-01-06 Resized the Chyrosran22 image to be the same as assembled_switch.gif
2022-01-10 Added image of a 3D printed keycap to the README.
2022-01-10 Added additional bullet to the benefits of 3D printed keycaps in the README.
2022-02-18 Fixed an issue with the cherry_cross() module in that it was making the wrong side of the cross thicker than the other (basically it was the opposite of what it's supposed to be. Also improved the co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
    [body.scad, levitator.scad, stem.scad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]
2022-03-19 1.1 Release: Major changes to stabilizer.scad (it now works with low-profile switches) and you can now adjust the corner radius of the switch body. There were other minor changes (see the CHANGELOG a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
    [body.scad, stabilizer.scad, stem.scad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]
2022-06-26 Added new 'stem_void' feature for making 3rd party designs accept Void Switch stems and improved the stabilizer design with some new clips so that it can be used with low-profile Void Switches.
    [body.scad, stabilizer.scad, stem.scad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]
2022-08-03 Add var for managing wall thickness in sheath.
    [void_switch.scad]
2022-08-03 Add changelog note for PR.
    [void_switch.scad]
2022-09-12 Version 1.4: Added new SHEATH_TOLERANCE_TEXT parameter, changed the default MAGNET_VOID to 0.9, and included new pregenerated STL and 3MF files (see Changelog at the bottom of void_switch.scad for fu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
    [stabilizer.scad, stabilizer_4x2mm_-0.1_void_4mm-travel.3mf, stabilizer_4x2mm_-0.1_void_4mm-travel.stl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]
2024-08-31 VOID SWITCH 2.0! See the Changelog at the bottom of void_switch.scad for details on what changed.
    [body.scad, sheath.scad, sheath_negative.scad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]
